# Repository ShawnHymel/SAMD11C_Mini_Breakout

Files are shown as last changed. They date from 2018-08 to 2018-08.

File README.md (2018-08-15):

SparkFun SAMD11C14 Mini Breakout
========================================

SparkFun SAMD21 Mini Breakout

[*SparkFun SAMD21 Mini Breakout (DEV-13664)*](https://www.sparkfun.com/products/13664)

The SAMD21 Mini Breakout is a [Pro Mini](https://www.sparkfun.com/products/11114)-sized breakout for the Atmel [ATSAMD21G18](http://www.atmel.com/devices/ATSAMD21G18.aspx), a 32-bit ARM Cortex-M0+ processor with 256KB flash, 32KB SRAM, and an operating speed of up to 48MHz. The SAMD21 is compatible with the Arduino IDE, and libraries for the Arduino Zero.

Repository Contents
-------------------

* **/Documentation** - Data sheets, additional product information
* **/Firmware** - SAMD21 Arduino Bootloader
* **/Hardware** - Eagle design files (.brd, .sch)
* **/Production** - Production panel files (.brd)

Documentation
--------------
* **[Hookup Guide](https://learn.sparkfun.com/tutorials/samd21-minidev-breakout-hookup-guide/resources--going-further)** - Basic hookup guide for the SAMD21 Mini Breakout.

Product Versions
----------------
* [DEV-13664](https://www.sparkfun.com/products/13664) - Initial product release - v10.
* [DEV-13672](https://www.sparkfun.com/products/13672) - The SparkFun SAMD21 _Dev_ Breakout -- a similar, Arduino-shaped version of this board.

Version History
---------------
* [v1.0](https://github.com/sparkfun/SAMD21G_Mini_Breakout/tree/v10) - Initial release 

License Information
-------------------

This product is _**open source**_! 

Please review the LICENSE.md file for license information. 

If you have any questions or concerns on licensing, please contact techsupport@sparkfun.com.

Distributed as-is; no warranty is given.

- Your friends at SparkFun.

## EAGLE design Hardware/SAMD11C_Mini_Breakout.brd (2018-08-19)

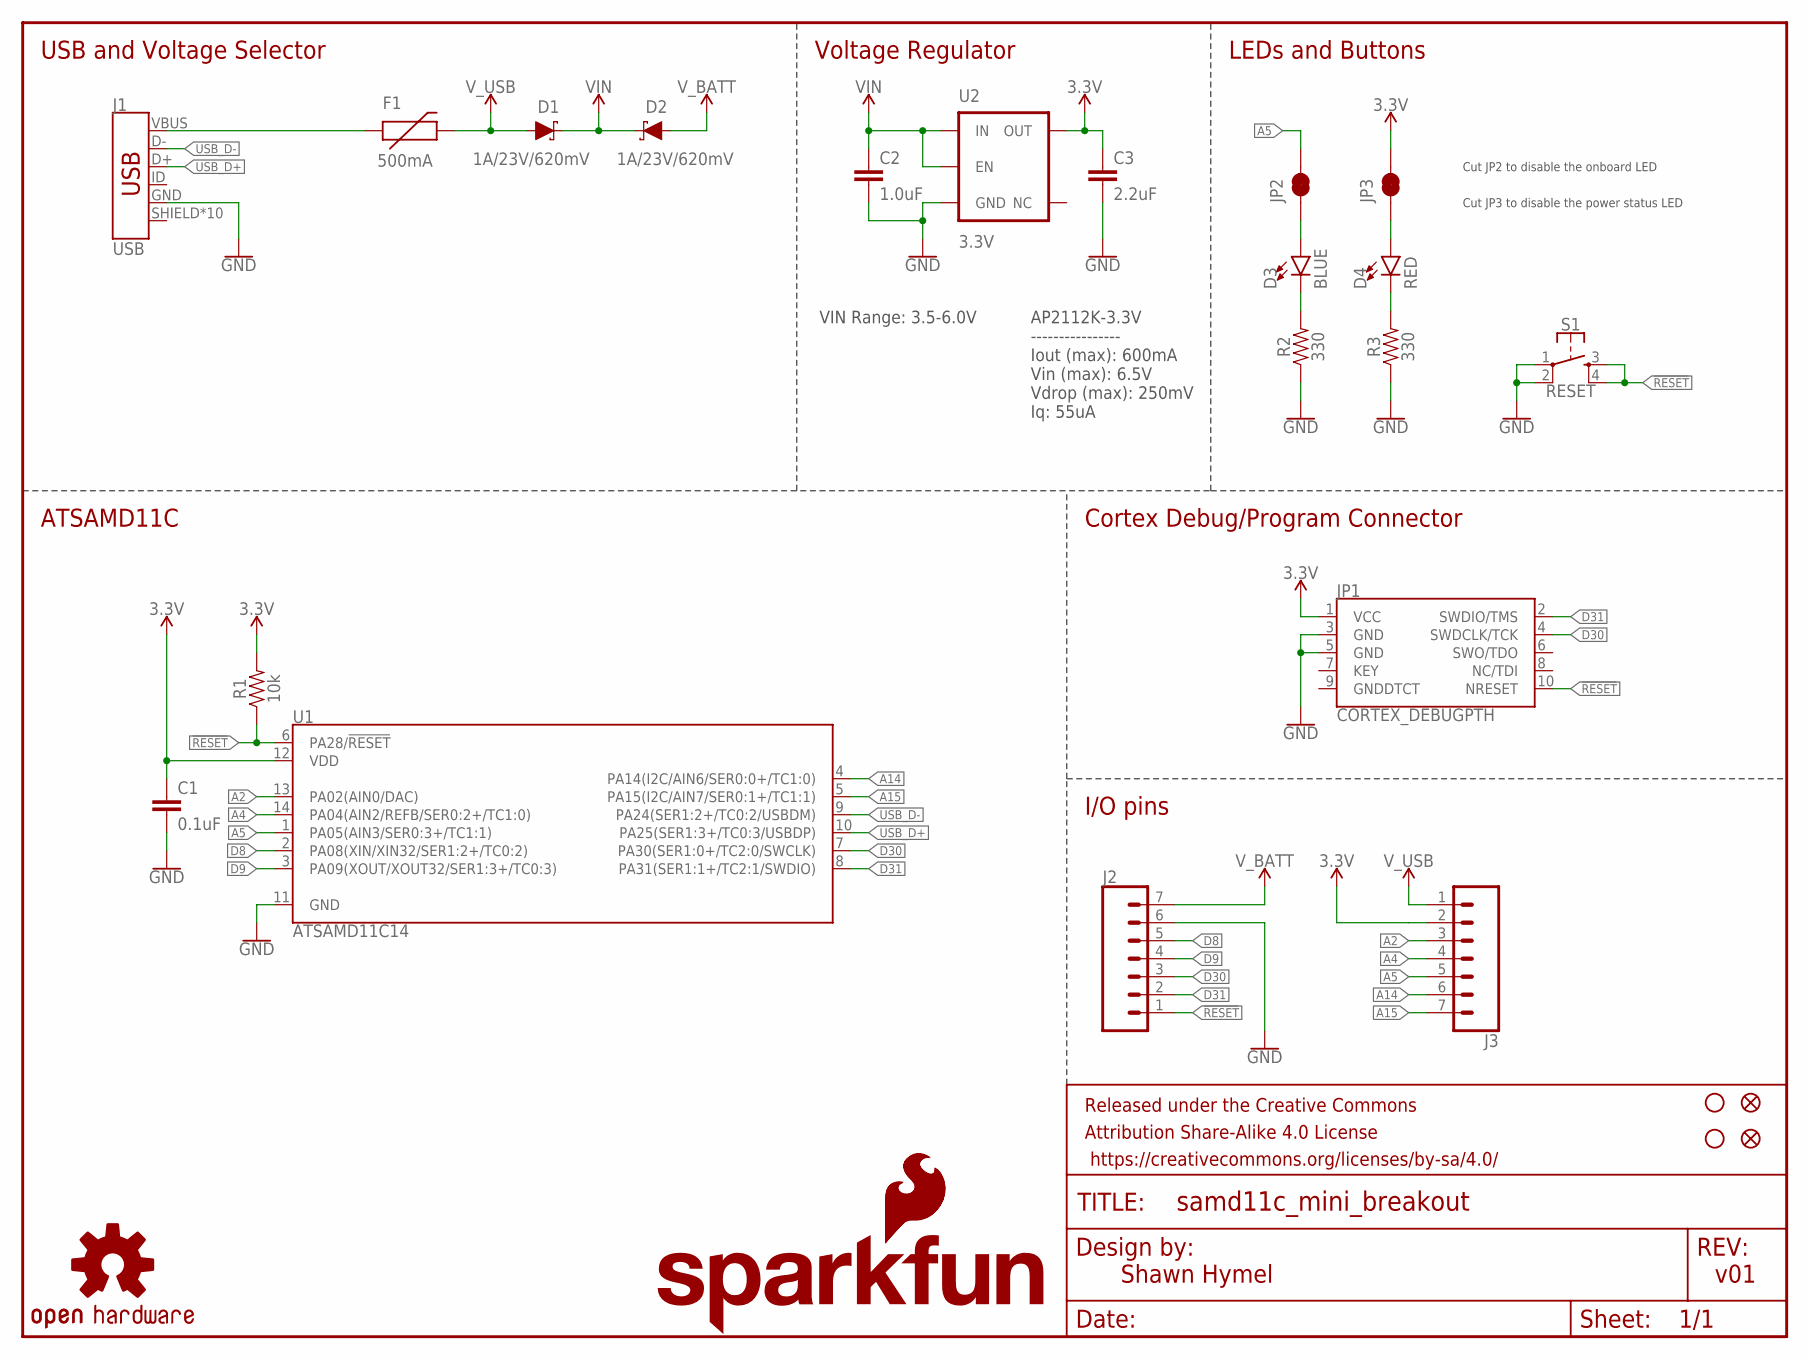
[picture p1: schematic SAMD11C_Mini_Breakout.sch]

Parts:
C1: 0.1uF; 0603
C2: 1.0uF; 0805
C3: 2.2uF; 0603
D1, D2: 1A/23V/620mV; SOD-323
D3: BLUE; LED-0603
D4: RED; LED-0603
F1: 500mA; PTC-1206
FD1, FD2: FIDUCIAL1X2; FIDUCIAL-1X2
FRAME1, FRAME2: FRAME-LETTER; CREATIVE_COMMONS
H3, H4: STAND-OFF
J1: USB; USB-MICROB-PTH-MILL
J2, J3: CONN_07NO_SILK; 1X07_NO_SILK
JP1: CORTEX_DEBUGPTH; 2X5-PTH-1.27MM
JP2, JP3: JUMPER-SMT_2_NC_TRACE_NO-SILK; SMT-JUMPER_2_NC_TRACE_NO-SILK
LOGO1: OSHW-LOGOS; OSHW-LOGO-S
LOGO2: SFE_LOGO_NAME_FLAME.1_INCH; SFE_LOGO_NAME_FLAME_.1
LOGO3: SFE_LOGO_FLAME.1_INCH; SFE_LOGO_FLAME_.1
R1: 10k; 0603
R2, R3: 330; 0603
S1: RESET; TACTILE_SWITCH_SMD_4.6X2.8MM
U1: ATSAMD11C14; SOIC-14
U2: 3.3V; SOT23-5

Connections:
3.3V: C1.1, C3.1, J3.2, JP1.1 (VCC), JP3.2, R1.2, U1.12 (VDD), U2.5 (OUT)
!RESET: J2.1, JP1.10 (NRESET), R1.1, S1.3, S1.4, U1.6 (PA28/!RESET!)
A2: J3.3, U1.13 (PA02(AIN0/DAC))
A4: J3.4, U1.14 (PA04(AIN2/REFB/SER0:2+/TC1:0))
A5: J3.5, JP2.2, U1.1 (PA05(AIN3/SER0:3+/TC1:1))
A14: J3.6, U1.4 (PA14(I2C/AIN6/SER0:0+/TC1:0))
A15: J3.7, U1.5 (PA15(I2C/AIN7/SER0:1+/TC1:1))
D8: J2.5, U1.2 (PA08(XIN/XIN32/SER1:2+/TC0:2))
D9: J2.4, U1.3 (PA09(XOUT/XOUT32/SER1:3+/TC0:3))
D30: J2.3, JP1.4 (SWDCLK/TCK), U1.7 (PA30(SER1:0+/TC2:0/SWCLK))
D31: J2.2, JP1.2 (SWDIO/TMS), U1.8 (PA31(SER1:1+/TC2:1/SWDIO))
GND: C1.2, C2.2, C3.2, J1.GND, J2.6, JP1.3 (GND), JP1.5 (GND), R2.1, R3.1, S1.1, S1.2, U1.11 (GND), U2.2 (GND)
unnamed: D3.A, JP2.1
unnamed: D3.C, R2.2
unnamed: D4.A, JP3.1
unnamed: F1.1, J1.VBUS
unnamed: D4.C, R3.2
USB_D+: J1.D+, U1.10 (PA25(SER1:3+/TC0:3/USBDP))
USB_D-: J1.D-, U1.9 (PA24(SER1:2+/TC0:2/USBDM))
VIN: C2.1, D1.C, D2.C, U2.1 (IN), U2.3 (EN)
V_BATT: D2.A, J2.7
V_USB: D1.A, F1.2, J3.1

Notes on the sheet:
Shawn Hymel
v01
VIN Range: 3.5-6.0V
AP2112K-3.3V ---------------- Iout (max): 600mA Vin (max): 6.5V Vdrop (max): 250mV Iq: 55uA
ATSAMD11C
USB and Voltage Selector
Voltage Regulator
LEDs and Buttons
Cortex Debug/Program Connector
I/O pins
Cut JP2 to disable the onboard LED
Cut JP3 to disable the power status LED

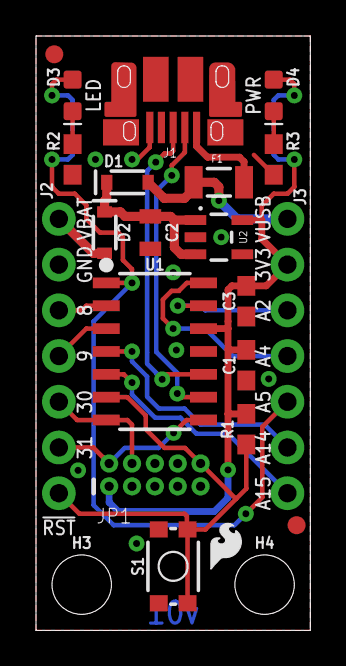
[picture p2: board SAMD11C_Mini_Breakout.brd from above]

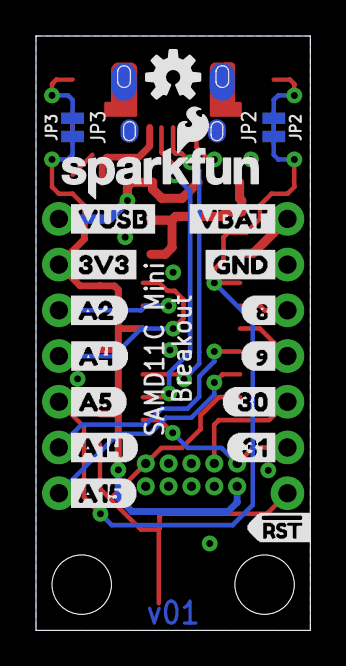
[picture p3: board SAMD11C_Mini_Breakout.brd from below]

Board: 2 copper layers, 15.2 x 33.0 mm, 43 parts (18 on the bottom side), 22 nets.

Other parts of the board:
U$1: #RST4
U$2: 3V33
U$3: 85
U$4: 96
U$5: 307
U$6: 318
U$7: A29
U$8: A410
U$9: A511
U$10: A1412
U$11: A1513
U$12: GND1
U$13: VBAT0
U$14: VUSB2

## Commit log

2018-08-15 Finished first draft of schematic
    [SAMD11C14_Mini_Breakout.brd, SAMD11C14_Mini_Breakout.sch]
2018-08-18 Changed up schematic to have less parts. Moved parts on board around
    [SAMD11C14_Mini_Breakout.brd, SAMD11C14_Mini_Breakout.sch]
2018-08-19 Finished layout for v01
    [SAMD11C14_Mini_Breakout.brd, SAMD11C14_Mini_Breakout.sch]
2018-08-19 Removed duplicate schematic
    [SAMD11C14_Mini_Breakout.sch]
2018-08-19 Renamed layout files to match repository
    [SAMD11C_Mini_Breakout.brd, SAMD11C_Mini_Breakout.sch]
2018-08-19 Moved some labales around. Sent out for protos. v01.
    [SAMD11C_Mini_Breakout.brd]

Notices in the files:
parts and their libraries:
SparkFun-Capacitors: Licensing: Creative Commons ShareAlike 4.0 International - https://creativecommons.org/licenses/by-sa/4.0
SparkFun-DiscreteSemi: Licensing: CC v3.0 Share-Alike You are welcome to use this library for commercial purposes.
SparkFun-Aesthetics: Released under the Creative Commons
